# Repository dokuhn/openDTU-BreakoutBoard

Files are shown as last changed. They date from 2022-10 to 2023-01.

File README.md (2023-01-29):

# openDTU Breakout Board

 [][cc-by-nc-sa]

To read Hoymiles inverters there is a nice project called [OpenDTU](https://github.com/tbnobody/OpenDTU) which uses an ESP32 to talk to them. 

<br>

To extend this project with a hardware component this small KiCAD board was created. With it it should be possible for the not experienced in soldering person to build an own OpenDTU easier. But also the possibility to add further ideas, like temperature sensors, display etc.. In a second step it is also possible to design a board with all the necessary components on it directly. 

<br>

The first batch of 10 pieces is partially built and tested. Further tests will follow. Extensions of the board will be maintained in a second branch. 

<p align="center">

</p>

## Donations

As you can see I am in the process of developing a SMT/SMD variant. To support the first 10-25 prototype boards you are welcome to make a donation. This donation should be used to compensate the material costs for components, boards and consumables (soldering paste, etc.). Through my membership in the [Linux User Group Saar e.V.](https://lugsaar.de/) you support more than just me, you also support our community in similar creative and technical projects in the open source and open hardware domain. 

-PayPal: 

## Renderings

<p align="center">
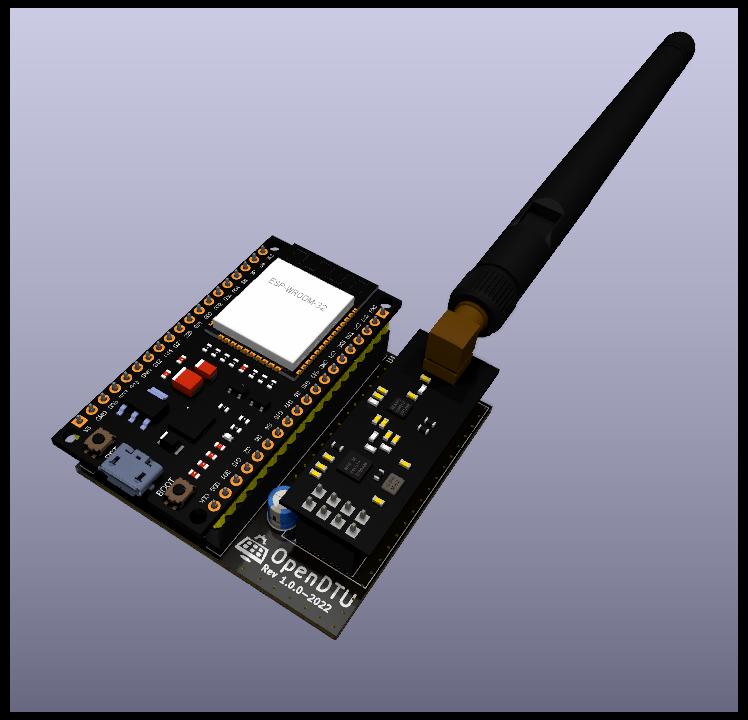
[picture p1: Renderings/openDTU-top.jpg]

</p>

<p align="center">
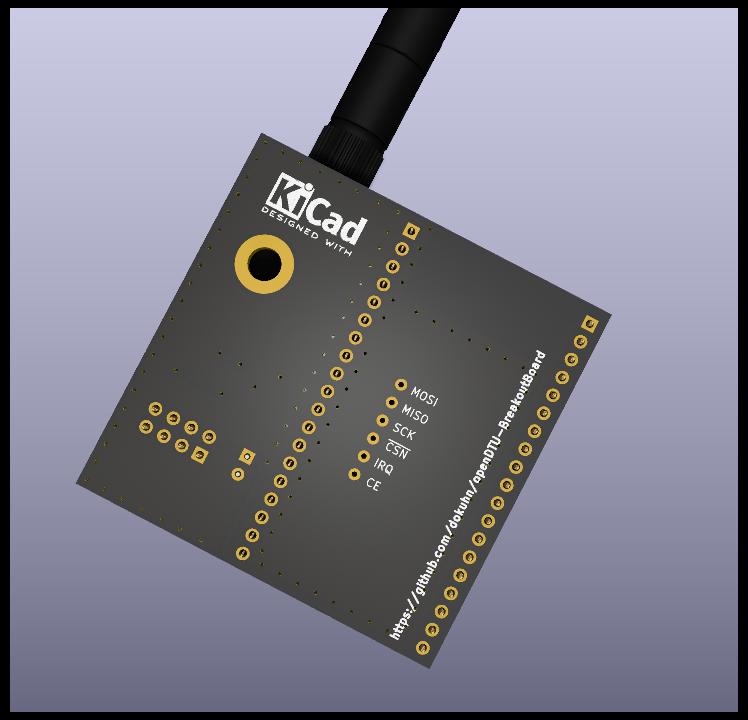
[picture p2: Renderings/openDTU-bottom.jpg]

</p>

## Development

As described in the previous section, extensions or development stages are maintained in a separate branch. This section is to show exemplarily where the current developments are. Currently a SMD/SMT variant of the board is designed (see picture with the first placement). The SMT will make the board much smaller of course, so it will fit into small cases. All needed components for operation will be on the board. 

### New Features:

- All components on just one board
- Stable voltage supply
- MicroSD slot with support for a small file system to store e.g. measurement series (CSV or JSON files)
- USB-C (now more common than microUSB)
- Option to connect a small (I2C) display

<p align="center">

</p>

##  Hardware you need

### ESP32 board

In principle, the hardware recommended [here](https://github.com/tbnobody/OpenDTU) has been used in this project. Unfortunately there are many different variants, especially in the MCU boards, so that you must be very careful that your board is pin-compatible with the following figure. 

<p align="center">
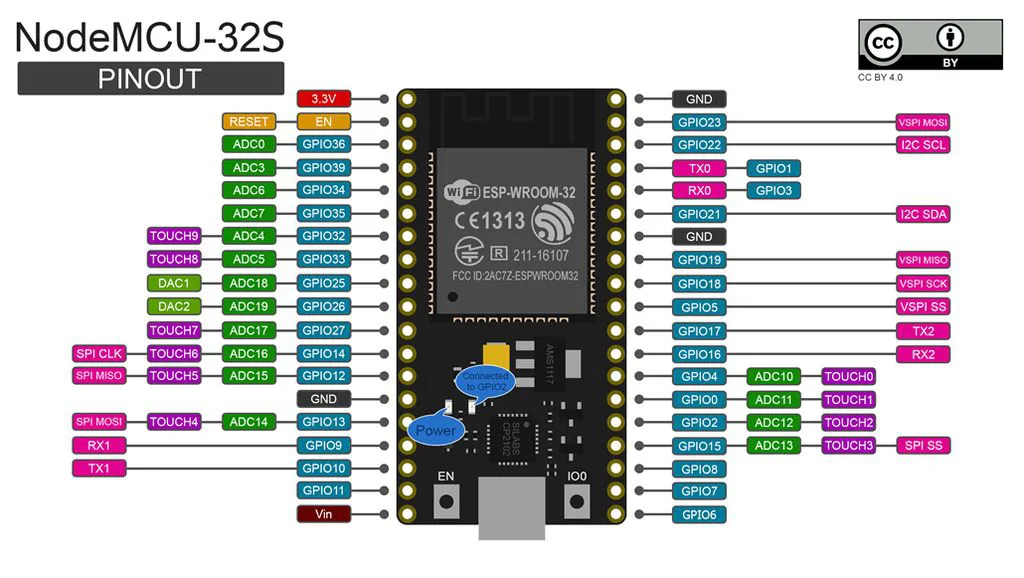
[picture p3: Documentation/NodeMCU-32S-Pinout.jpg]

</p>

[figure source](https://i0.wp.com/www.teachmemicro.com/wp-content/uploads/2020/06/NodeMCU-32S-Pinout.jpg?ssl=1)

### Capacitor

As you can see in the graphics above, an electrolytic capacitor is placed between the two boards. This capacitor should be as close as possible to the NRF24L01+ radio board. The size of the capacity should not be larger than 100 uF, typically capacity like 10uF or 22uF are recommended. This also corresponds to the typical capacity in the AP1117 datasheets (keep in mind that the noboard capacity of the ESP32 board has to be added). The voltage stability has to be higher than 3.3V, so all common 5V, 6.3V, 6.5V, 10V, 25V or even 50V are more than enough. 

## Case

<p align="center">
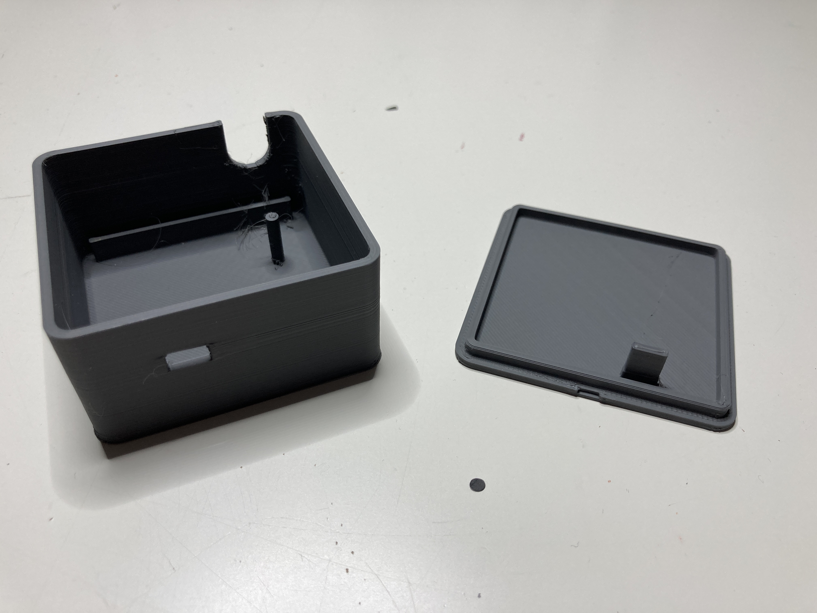
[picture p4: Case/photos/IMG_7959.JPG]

</p>

<p align="center">
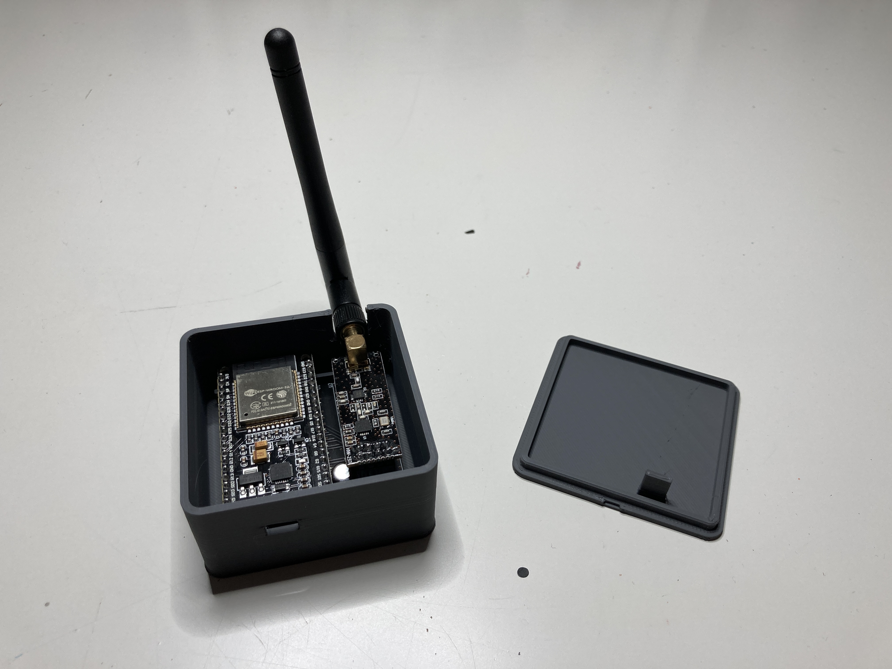
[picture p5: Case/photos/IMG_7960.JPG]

</p>

<p align="center">
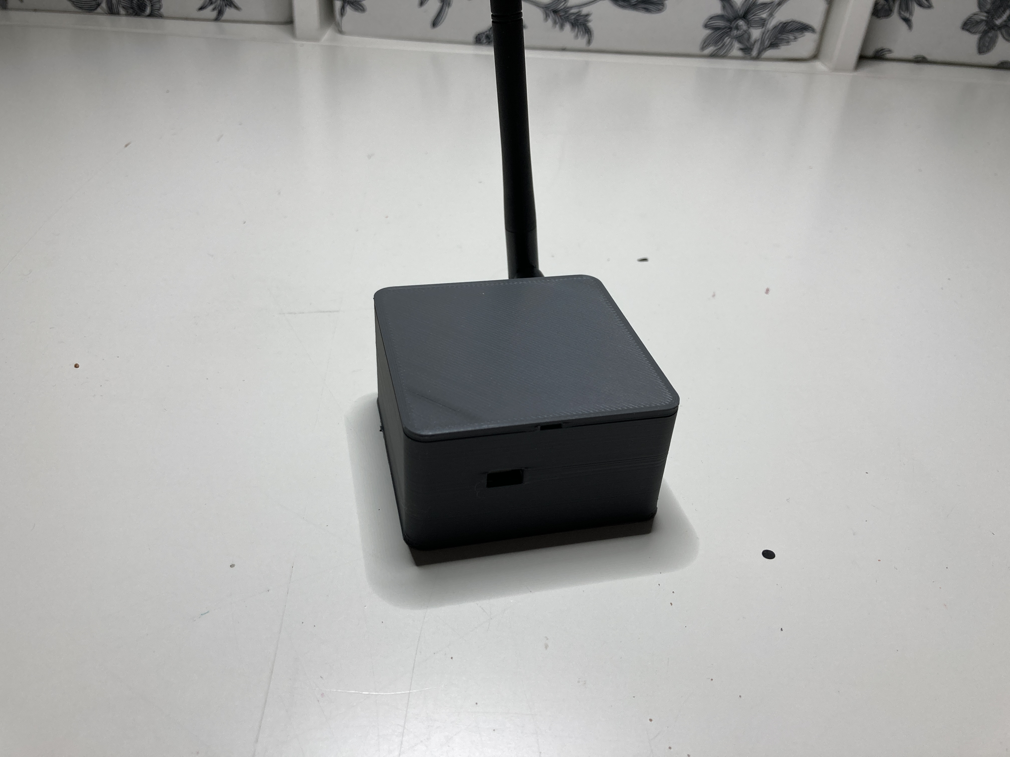
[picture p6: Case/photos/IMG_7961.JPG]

</p>

## License 

This work is licensed under a
[Creative Commons Attribution-NonCommercial-ShareAlike 4.0 International License][cc-by-nc-sa].

[][cc-by-nc-sa]

[cc-by-nc-sa]: http://creativecommons.org/licenses/by-nc-sa/4.0/
[cc-by-nc-sa-image]: https://licensebuttons.net/l/by-nc-sa/4.0/88x31.png
[cc-by-nc-sa-shield]: https://img.shields.io/badge/License-CC%20BY--NC--SA%204.0-lightgrey.svg

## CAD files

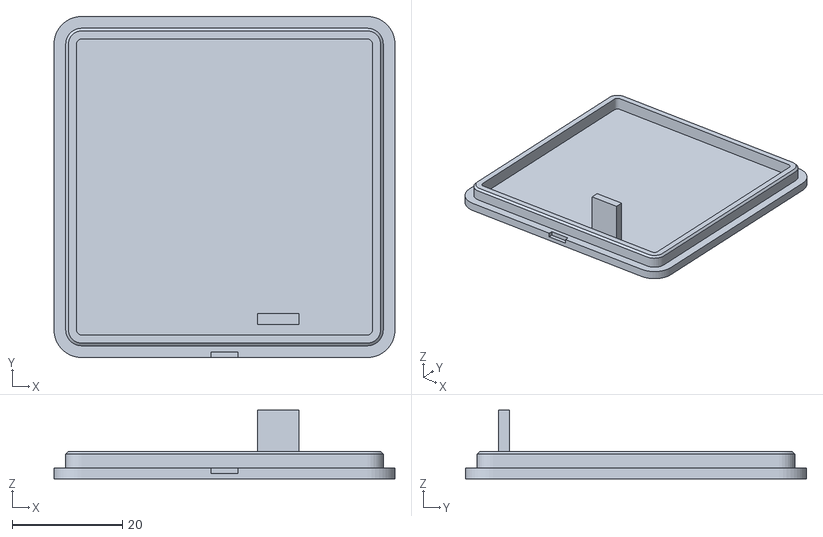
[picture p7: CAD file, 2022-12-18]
Case/STL/case-lid.stl
62.0 x 62.0 x 12.5

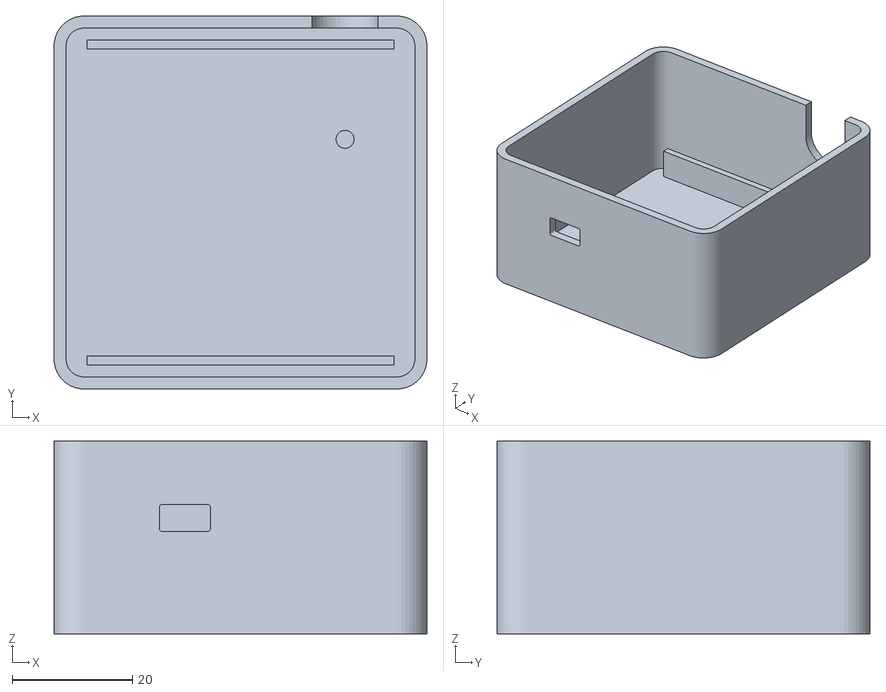
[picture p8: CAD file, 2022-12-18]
Case/STL/case.stl
62.0 x 62.0 x 32.0

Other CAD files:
Case/STL/dtu-case-fusion360-archive.f3d

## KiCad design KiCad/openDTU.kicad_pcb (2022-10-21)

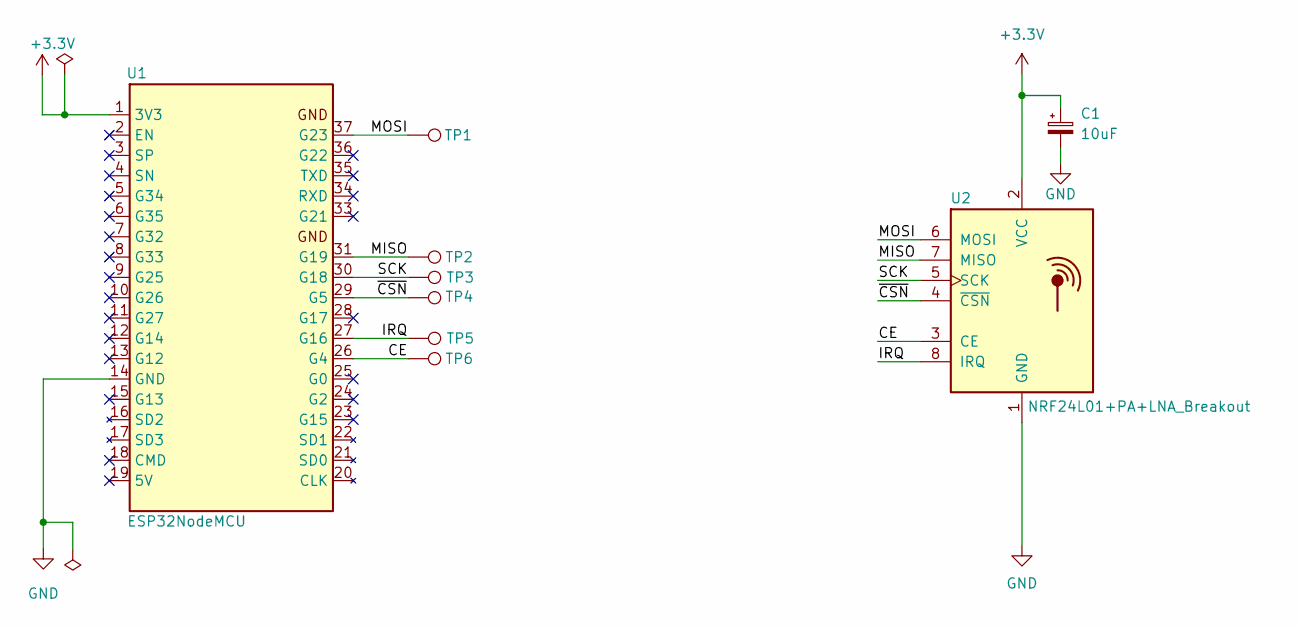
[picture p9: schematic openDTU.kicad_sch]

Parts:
C1: 10uF; CP_Radial_D5.0mm_P2.50mm
TP1, TP2, TP3, TP4, TP5, TP6: TestPoint; TestPoint_THTPad_D1.5mm_Drill0.7mm
U1: ESP32NodeMCU; ESP32-NodeMCU_WROOM_32
U2: NRF24L01+PA+LNA_Breakout; nRF24L01+PA+LNA_Breakout

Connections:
+3.3V: C1.1, U1.1 (3V3), U2.2 (VCC)
/CE: TP6.1, U1.26 (G4), U2.3 (CE)
/IRQ: TP5.1, U1.27 (G16), U2.8 (IRQ)
/MISO: TP2.1, U1.31 (G19), U2.7 (MISO)
/MOSI: TP1.1, U1.37 (G23), U2.6 (MOSI)
/SCK: TP3.1, U1.30 (G18), U2.5 (SCK)
/~CSN: TP4.1, U1.29 (G5), U2.4 (~CSN)
GND: C1.2, U1.14 (GND), U1.32 (GND), U1.38 (GND), U2.1 (GND)

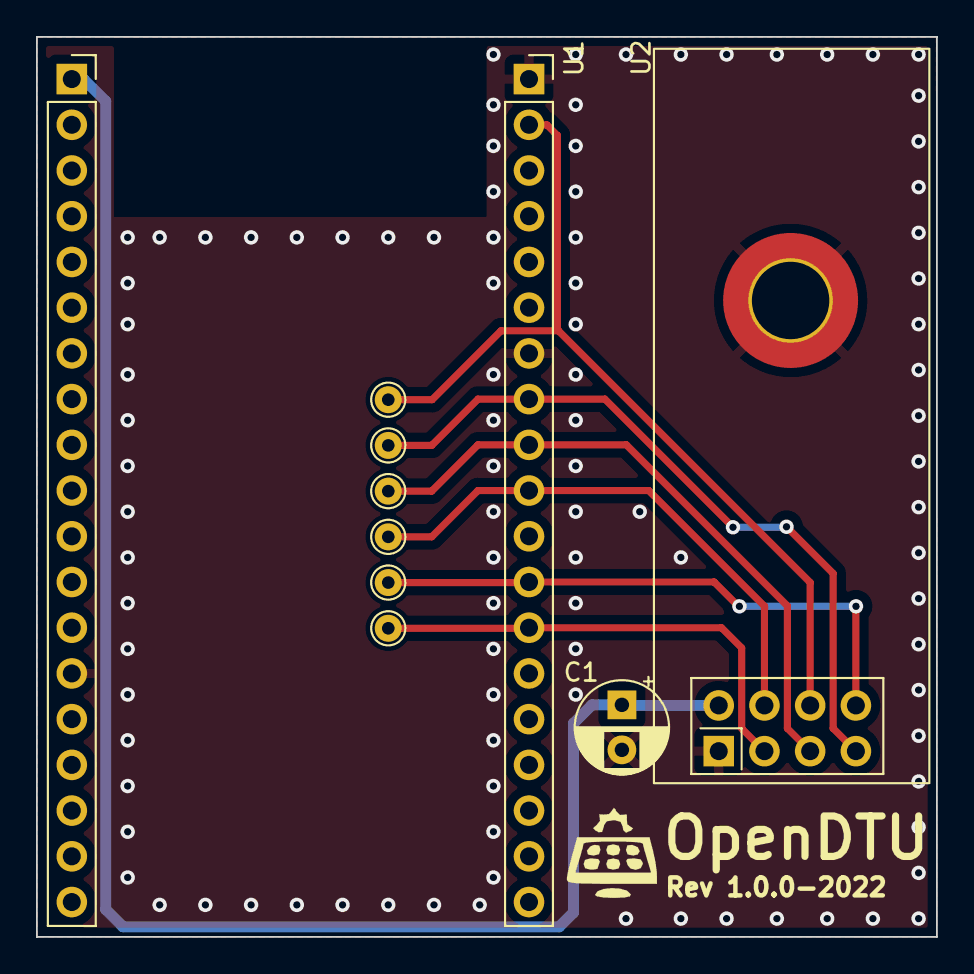
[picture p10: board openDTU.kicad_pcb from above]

Board: 2 copper layers, 50.0 x 50.0 mm, 9 parts (0 on the bottom side), 8 nets.

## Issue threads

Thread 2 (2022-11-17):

PCB's available for sale?

bjoerns1983, 2022-11-17:
Hi there,
i love your idea, because i was just about designing the same but as far not as professional as yours because i have never done that before.
Just have two questions:
1. Dow you have some boards for sales, i would need 3 units.
2. Would is be possible possible to change the position of the cap so that also higher ones could be mounted
3. In some forums i have read that beside the elctrolyte cap also a ceramic one should be place infront of the NRF.

bjoerns1983, 2022-11-18:
I would to take the two board you have left over, or is there a gerber file etc. which only needs to be uploaded to jlpcb etc. to get them manufactured.
Sorry if the question might be dumb i have never done that before.

Really love the simplicity of the adapter.

dokuhn, 2022-11-18:
I can send you two boards and the right capacitors for some small bucks. If necessary I will order more boards soon. That depends on the requirements in my network with friends and colleagues.

bjoerns1983, 2022-11-19:
That would be awesome, simply tell me what you get incl. shipping in Germany.
Are there private messages on Github so would could clearify the details?

dokuhn, 2022-11-20:
You can send me a mail at [dominik.kuhn90@googlemail.com](mailto:dominik.kuhn90@googlemail.com), then we can coordinate details about shipping etc.

dirkheiden, 2022-11-26:
It’s not very difficult to order these PCB from i.e. Aisler. The capacitors can be ordered on eBay for example.
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

bjoerns1983, 2022-12-06:
Okay after waiting for ages for the Pinheaders it done:
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

bjoerns1983, 2022-12-19:
If anybody is interested: I have ordered some boards myself and have some left over.
So if anyone wants to try it just drop me a mail to: 3ddruck@sengotta.net

MoritzLerch, 2022-12-24:
Old vs. New

Thanks to @bjoerns1983 for the PCB 😄

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

bjoerns1983, 2022-12-30:
Okay all gone here.

evilmumi, 2023-01-11:
Hi, are some PCB still available to buy?
Or can some1 tell me where / how i can order this best from .de
I only need one

Archibald-Harry-Tuttle, 2023-01-11:
I have some left.
Added mounting holes on all 4 corners for 3mm screws.
just write me pn pls.

evilmumi, 2023-01-11:
> I have some left. Added mounting holes on all 4 corners for 3mm screws. just write me pn pls.

Hi, a pn on github is not possible or?

Archibald-Harry-Tuttle, 2023-01-11:
> > I have some left. Added mounting holes on all 4 corners for 3mm screws. just write me pn pls.
>
> Hi, a pn on github is not possible or?

You find me in the discord server of OpenDTU repository.

guha7, 2023-01-12:
Does anybody one PCB left?
Thanks for your offer!

Archibald-Harry-Tuttle, 2023-01-12:
I have some left.
like in the last post before,
you find me on discord.

webwerb, 2023-01-18:
Sorry, ich bin zu blöd den Ansprechpartner zu finden ....

Ich bräuchte insgesamt 3 Platinen für folgende Konfiguration
- Espressif ESP32 WLAN Dev Kit Board Development Bluetooth Wifi v1 WROOM32 Node MCU
- NRF24L01+ PLUS - PA LNA SMA Antenne Long Range Funk Modul Raspberry Arduino
- 0,96 Zoll OLED Display I2C SSD1306

Ev. auch 3 Gehäuse für Nutzung mit Display, da ich noch keinen Drucker habe.

Wäre dankbar für entsprechende Tips für einen Anfänger hier auf der Platform.

Danke!

dokuhn, 2023-01-18:
Hi, you are not too stupid to find the contact person.

Thank you for your request. I am the contact person for this repo, but as you may have seen, this is a community driven project. That means members of the community support each other with for example boards or even questions about variants etc.. In the "home" README file is described for which board this breakout board is intended. Is your board compatible with it ? There are also other variants with less pins which can be used by a small hack of the board. For this you can have a look at the corresponding issue. Otherwise @Archibald-Harry-Tuttle  as you can see above probably still board left. You can reach him under the following [Discord link](https://discord.gg/WzhxEY62mB). I currently have no more boards left, new ones are on the way and will take more than 10 days to arrive.

Dominik Kuhn

Pixel-Chris, 2023-01-26:
@dokuhn
Hi, sind die Boards reinzufällig schon angekommen?

webwerb, 2023-01-26:
Moin,

gerade eingetroffen.

Super schnell – Danke!

Ich Dussel hab natürlich vorher nicht geschaut ob 30 oder 38 Pin und ich hab natürlich die 30 Pin Version vom ESP32 ….

Das wird dann so nicht passen?

Also 30 Pin Borads kaufen (wo?) oder 38 Pin ESP 32 kaufen. Dann könnte ich gleich welche mit externer Antenne fürs WLAN nehmen.

Grüße

Uwe

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

dokuhn, 2023-02-01:
Nachdem in Fernost auch das neue Jahr vorbei ist, hab ich eine Mail bekommen, dass die nächsten Platinen unterwegs sind zu mir. Sprich die 20 Platinen des normalen Breakout-Board werden demnächst dann eintreffen. Die SMD Variante ist in den letzten Zügen und wird in den nächsten Wochen ebenfalls als Prototypen mal aufgebaut.

dirkheiden, 2023-02-01:
Auf die SMD Version freue ich mich sehr. Hast Du dafür schon eine BOM?

wiedimot, 2023-02-11:
>

@dokuhn wie kann man die Boards denn bei dir bestellen?
Ich hätte auch interesse an 3 Stück. In dem Fall die "normale" Version des Breakout Boards.

dokuhn, 2023-02-12:
@wiedimot aktuell hab ich von der normalen Variante noch gut 15 Stück "vorrätig". Du kannst du mir einfach eine persönliche Mail schreiben. Darin kannst du mir dann auch die Adresse etc. mitteilen wo das Ganze hin soll. In der Mail können wir dann klären ob du mir etwas überweist oder den PayPal Button nutzen möchtest.

Auch wenn meine Platinen bei mir mal temporär aus sind, ist es so, dass die Community sich da behilflich sehr behilflich ist. Ich werde entsprechenden Link die Tage mal erweitern in der README damit die ganzen Channel auch gefunden werden können.

andreas-bulling, 2023-02-17:
Hallo zusammen - ich hätte auch Interesse an einem Bord. Die normale Version würde mir reichen - sind noch welche da?

dokuhn, 2023-02-17:
Wie in der Message zuvor beschrieben bitte ein persönliche  E-Mail an mich, dann können wir Details wie Adresse etc. dort auf dem kurzen Weg klären.

### Kurzes Update:
Aktuell sind noch rund **6-7 Boards** übrig.  Ich würde nochmal welche Bestellen. Ansonsten bitte nicht wundern, ich besorge jetzt keine hunderte der Boards in der Phase, in der ich Beschaffungen tätige für die SMD/SMT Variante. Aus diesem Grund gibt es meiner Seitz lediglich Losgrößen zwischen 20 - 50 Platinen.

huckes, 2023-02-20:
Hallo,
hatte auch Interesse an drei Boards per PM vor ein paar Tagen bekundet, leider bisher keine Antwort. Mail ist evtl. untergegangen oder ich bin zu ungeduldig?

dokuhn, 2023-02-20:
### **Update:**

Die letzte Bestellung ist jetzt mehr oder weniger kommplett raus. Sprich das letzte BreakoutBoard liegt schon im Hausgang für den Weg zur Post. Ich danke allen für die Unterstützung des Projekts an dieser Stelle. Die nächsten Boards sind aktuell wohl in der Produktion und werden vorausichtlich Ende nächster Woche eintreffen.

The last order is now more or less completely shipped. The last BreakoutBoard is already in the corridor on its way to the post office. I would like to thank everyone for their support of the project. The next boards are currently in production and will probably arrive at the end of next week.

dokuhn, 2023-03-16:
### **Update:**

Die neue Variante ist mal prototypisch aufgebaut und wird getestet. Auch wenn es inzwischen schon merklich länger hell ist abends, könnte das Bild besser sein um 21 Uhr. ;-)

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

dokuhn, 2023-03-21:
Ich freue mich das die neue Variante auf Interesse stößt. In Summe sind jetzt 4 Boards aufgebaut und werden durch unterschiedliche Kollegen der Community und im Umkreis des Vereins auf Herz und Nieren getestet. Danach (in den nächsten 1 - 2 Wochen) wird es ein Batch geben welches wir fertig bestückt bei Aisler und Co. Beschaffen. 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

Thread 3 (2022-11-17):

Specs of C1?

dersch81, 2022-11-17:
Hi, what are the specs of C1?

dokuhn, 2022-11-18:
Hi, i used a capacitor with 22uF and 50V voltage resistance, I had many of them at home. But a capacitor with 10uF and 6.3V is a good choice.

stefan123t, 2022-11-28:
We usually recommend 47-100uF on the Discord but that is just word of mouth. I guess anything between 10 and 100uF should be sound.
@dokuhn thanks for the board!
Are there plans to leave a bit more space for the Elko ?
currently it does not fit easily between the MCU and NRF boards.
Thanks time and again for your contribution !

If you change the layout it may be good to have the six Test-Pins under the board as removable solder bridges so someone could use a different Pinout between MCU and NRF.

Closed 2023-03-09.

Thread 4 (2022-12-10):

Include female pin headers

mojoaxel, 2022-12-10:
_First let me thank @dokuhn for creating this board! I've already ordered a handfull and It's amazing._

Now I would like to order some breakout boards where I can simply plug-in the ESP32 and the nRF24L01+ boards without the need to solder. For that fitting straight PCB sockets/pin-headers are missing in the schematics.

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

Is there a way to add them to the KiCad projekt so that they easily can be manifactured from any PCB- and assembly-service?
Sadly I don't have any experiance with KiCAD, yet and I'm afraid that I make a stupid beginer mistake.

dokuhn, 2022-12-16:
I thank you for your idea. typically, the schematic is to show the logical connection of electronic components. This is made by the SPI etc. Connection of the two breakout board.  Pin headers etc are part of the physical expression and therefore part of the footprint. At this point one could design a corresponding footrpint with just the pin headers, but it is not really usual.

Many PCB companies that offer assembly limit the assembly to SMT/SMD. Or do you know a cheap company that solder THT components ? For the future there should be a complete SMD variant.

Closed 2023-01-02.

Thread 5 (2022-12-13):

3D Print Case

bjoerns1983, 2022-12-13:
Just as info i have designed a 3D Printable Case for the Breakout board. If the next testprint is okay, i will send you a PR with the STL and Fusion 360 Files.

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

Bonze255, 2022-12-16:
holes for wall mounting on the underside would still be good .. :)

dokuhn, 2022-12-16:
Thank you for your feedback. The case looks very cool. I will adjust the file structure so that KiCAD files and CAD etc. are separated from each other in directories. This makes it easier with the PR and the linking in the README file.

bjoerns1983, 2022-12-18:
#7
Okay PR is created. I have no added any hole for mounting because i dont want the screws to short anything.
Prints quite fast. If any modification is neede the fusion 360 files are included.

bjoerns1983, 2023-01-10:
Yeah no problem, simply tell me what you need.

CodeFinder2, 2023-02-03:
A version with an OLED display cutout would also be cool :)

bjoerns1983, 2023-02-04:
I dont have such a board. If you have on, grab the Fusion360 Files, modify them, testprint them and send a PR.

huckes, 2023-02-20:
Hello, I droped a remix of Bjoerns design with an opening for 1.3" OLED display to Thingiverse: https://www.thingiverse.com/thing:5866231

CodeFinder2, 2023-02-20:
Looks like it is an 0,96" display. Do you have a link to the display you used/showed in the photo?

Thank you very much for sharing! 😊

bjoerns1983, 2023-02-20:
> Hello, I droped a remix of Bjoerns design with an opening for 1.3" OLED display to Thingiverse: https://www.thingiverse.com/thing:5866231 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

Cool, maybe you could drop a PR so it could be added to the Repo?

huckes, 2023-02-20:
Hi,

@CodeFinder2**:  it is a 1.3" display, rather fast delviered from China: https://de.aliexpress.com/item/4001145494936.html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

@bjoerns1983 : Currently it's just a Q&D remix. I try to refine it a bit (e.g. covering the lower part of the glass where nothng is displayed). When more or less final, I'll drop a PR. In the meanwhile the lid is available under Thingiverse.

I also want to test it completely set up with the hardware, as I'm not certain if the pins of the display come in conflict with the ESP-module.

bjoerns1983, 2023-02-20:
Ah okay thats why it is tagged WIP.

dokuhn, 2023-02-20:
very cool job, i am very happy to see cool extensions to the project. Feel free to post a PR when it's tested so we can add it to the repo. This way a lot of people will get something from it.

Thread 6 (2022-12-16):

Make Breakout-Board  also available for Wemos D1

Bonze255, 2022-12-16:
Its possible to add the Wemos D1 Layout between the Pinouts of the NodeMCU Board?

dirkheiden, 2022-12-31:
No, it is not. The Demos D1 is a ESP8266 board. OpenDTU makes use of the ESP32.

Closed 2023-02-03.

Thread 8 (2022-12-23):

Mention the boards that fit to the layout

erniberni, 2022-12-23:
It would be wise to mention the boards that fits to the layout
Users should compare the pinout before connecting
This one is fine -> https://www.az-delivery.de/products/esp32-developmentboard
This one doesn't fit -> https://www.mischianti.org/2021/02/17/doit-esp32-dev-kit-v1-high-resolution-pinout-and-specs/
Take a special look at the connection of VCC and GND

dokuhn, 2022-12-27:
Thank you for the hint. I will add the corresponding entry to the README file at the next time. Additions or maintenance are welcome.

andy5macht, 2022-12-31:
I used ESP32 DEV KIT v1 and had to modify/bridge something. here is what i did:
first use these pins for ESP32 DEV KIT v1:
    -DHOYMILES_PIN_MISO=18
    -DHOYMILES_PIN_MOSI=23
    -DHOYMILES_PIN_SCLK=5
    -DHOYMILES_PIN_IRQ=4
    -DHOYMILES_PIN_CE=2
    -DHOYMILES_PIN_CS=17

Cut D19 from ESP32 DEV KIT v1 (otherwise D19 has short circuit to GND)
Scratch GND next to GND Pin of ESP32 DEV KIT v1 to connect GND of this BreakoutBoard to ESP32 DEV KIT v1.
Solder 3V3 Pin of ESP32 DEV KIT v1 to Elko (positive side)
If all done this should work an look like this:
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

stepl, 2023-01-18:
Does any of you could help me to understand what's difference between these 2 boards and if they fit?
- [ESP-32 Dev Kit C V4](https://www.az-delivery.de/products/esp-32-dev-kit-c-v4?variant=30871551869024)
- [ESP32 NodeMCU](https://www.az-delivery.de/products/esp32-developmentboard?variant=36542176914)

From the pin layout to me it's look like both fit the layout but would still be good to get a confirmation and to understand what differences are between the NodeMCU and the V4 version?

jelli123, 2023-01-18:
The second one is the "ESP32 Dev Kit C V2". Beside some improvements it should work like the first one.
[Schematic V4](https://cdn.shopify.com/s/files/1/1509/1638/files/ESP-32_NodeMCU_Developmentboard_Schematic_korr.pdf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)
[Schematic V2](https://dl.espressif.com/dl/schematics/esp32_devkitc_v4-sch.pdf)

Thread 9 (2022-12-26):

Publish PCB top and Bottom as *.dxf or *.svg

HaraldNoack, 2022-12-26:
Hello,
please can you export the kicad-PCB file to top and button svg or dxf (best both) gerber is also an option.

Then everyone can make the pcb.

Thanks for your work!

Best Regards
Harald

dokuhn, 2022-12-27:
Thank you for your request. The current Gerber files of the last release (with exactly these data the boards are produced) can be found [here](https://github.com/dokuhn/openDTU-BreakoutBoard/releases/tag/1.0.0) In one of my next pushes, I can also put SVG or DXF files there. But I can't give any guarantee for this export. The currently provided data were

a) used by me for the production and
b) by some people from the community.

Best Regards

Dominik

Closed 2023-01-02.

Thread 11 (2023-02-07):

Wemos D1 compatible Version

bjoerns1983, 2023-02-07:
Hi there,
i know many people are waiting for the SMD Version of the adapter, which looks like a really cool project.
But to be honest i dont think that could be assambled at home any more, and if i look at other projects like ebusd, when chip shortage hits you there is a problem.

On the other hand we have a really simple adapter board which could be assambled at home using components you can buy for under 10€ at big commercial resellers. Thats really DIY and there was no shortage of these components in the past years.

A problem that occured with the adapter board was that there are boards that looks similiar, if you dont look really close, but they are not the same.

Long story short. The formfactor of the Lolin/Wemos D1 Mini was constant about the last few years. There are many clones of this board but they all share the same formfactor and pinout. There is also a D1 Mini32 which features the ESP32 Chipset.
https://www.wemos.cc/en/latest/d1/d1_mini.html
https://www.az-delivery.de/products/esp32-d1-mini

So what i like to ask: Would it be possible to adapt the standard Breakout Board to that formfactor and maybe add a Pinheader for Displays that are mentioned by the OpenDTU Project?

bjoerns1983, 2023-02-20:
@dokuhn any Idea if that would be a doable solution?
I would do it myself but i have ne experience regarding Kicad.

dokuhn, 2023-02-20:
Sorry for the late feedback. I was a little busy with the ordering of the parts for the SMT variant etc. I like your idea and can totally imagine that we will expand this as soon as the testing of the SMT variant is completed.

thomic, 2023-03-07:
just my 2 cents, I think D1Mini isn't a bad form factor, but a "breakout board" has so many downsides, like broken boards (PINs) or connection issues after some time - so in the end - it makes a lot of sense to have a DIY solution based on the SMT/SMD version
Just get a board, possibly pre-assembled already, and start flashing it.
In my mind, it should be as easy as flashing a Tasmota device or WLED onto an existing device. Not having to a lot to solder or break before.
Sure, the breakout board will still be alive and I guess will see some iterations, but as you need to have at least some soldering skills and like 1 hour to assemble everything, it won't be that much straight forward as a SMT variant.

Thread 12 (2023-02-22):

Add a OLED Version

dersch81, 2023-02-22:
Hi, since OpenDTU is now supporting displays I suggest to add an additional Display version of the Case and PCB to have the connector breakouts as well as mounting points with a cut out of the case lid.

I would support a cheap an common one like this: https://www.amazon.de/dp/B01L9GC470/ref=pe_27091401_487024491_TE_item

dersch81, 2023-02-24:
Ok, i have noticed the case lid with space for the OLED: https://www.thingiverse.com/thing:5866231

So why not adding it here? And just modify the PCB to have a Pinout to connect the OLED?

huckes, 2023-02-24:
Hi, please find the updated version here: https://www.thingiverse.com/thing:5866226.

I also changed the case, as the ESP-boards I had in stock are shorter and more slim as the boards for which the case originally was designed. I'll state a PR for the PCB soon.

SteffMUC, 2023-02-28:
Just fyi, spent some time to add the display connection directly on the PCB, case is currently in preparation, however not yet perfectly fitting, nevertheless you can see the intermediate status and concept here:
https://github.com/SteffMUC/openDTU_wDisplay2

thomic, 2023-03-07:
This is something the SMT (or maybe even the breakout variant) of the board can feature in a future edition. At the moment the focus is a bit on getting the SMT version done and production ready, just to get boards to the people. Still it should be possible to add a display to the board later if you got some time, soldering skills and interest. But for now -as time for pet projects is limited- I guess OLED by default will not be there in the first round.

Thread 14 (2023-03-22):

Wrong voltage at USB-Seriell Interface IC

dokuhn, 2023-03-22:
After building the first boards, a strange error occurred, which only came up when operating the board via a simple USB power supply. After some research, the error could be isolated to a wrong voltage at the USB-serial IC. In this application the IC must not be operated with USB typical 5V, it must be supplied with 3V3. So the Pins V3 and VCC must be connected to 3V3.

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

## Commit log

2022-10-03 first init
    [openDTU.kicad_pcb, openDTU.kicad_sch]
2022-10-04 connecting nRF24L01+ to the ESP32 in schematic
    [openDTU.kicad_pcb, openDTU.kicad_sch]
2022-10-21 adding OpenDTU Logo and some informations on the silkscreen
    [openDTU.kicad_pcb, openDTU.kicad_sch]
2022-10-21 chanching track width and adding mountinghole to support the NRF34L01+ Board
    [openDTU.kicad_pcb]
2022-10-21 Adding some Testpads for signals between ESP32 and nRF24L01+. Adding vias to connect Bottom and Top GND Copper Zone.
    [openDTU.kicad_pcb, openDTU.kicad_sch]
2022-10-21 Adding Gerber files for the first Order
    [openDTU-B_Cu.gbr, openDTU-B_Mask.gbr, openDTU-B_Paste.gbr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]
2022-11-20 change file structure
    [openDTU-B_Cu.gbr, openDTU-B_Mask.gbr, openDTU-B_Paste.gbr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]
2022-12-16 updating file structur
    [openDTU.kicad_pcb, openDTU.kicad_sch]
2022-12-18 Add 3d Print Files für OpenDTU case
    [case-lid.stl, case.stl, dtu-case-fusion360-archive.f3d]
2022-12-18 updating develop rendering and adding case photos to README.md
2023-01-13 adding some description of the recommended MCU board an capacitor

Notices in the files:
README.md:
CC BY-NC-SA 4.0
